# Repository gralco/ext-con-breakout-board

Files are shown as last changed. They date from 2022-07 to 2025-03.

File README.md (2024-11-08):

A breakout board for J10 on the Librem 5.

The rigid section has an overall thickness of 1.2mm, the flex section has an overall thickness of flex section is 0.126mm, and the stiffener and its adhesive adds 0.125mm on top of the thickness of the flex.

The panels were made by PCBWay, if you would like to order these yourself then you can use their product number W159429AS1D27 to reorder the same panel.

The FPC connector used is either Panasonic AXT624124 or OK-06M024-04.

Here is a photo of a v0.6 panel:
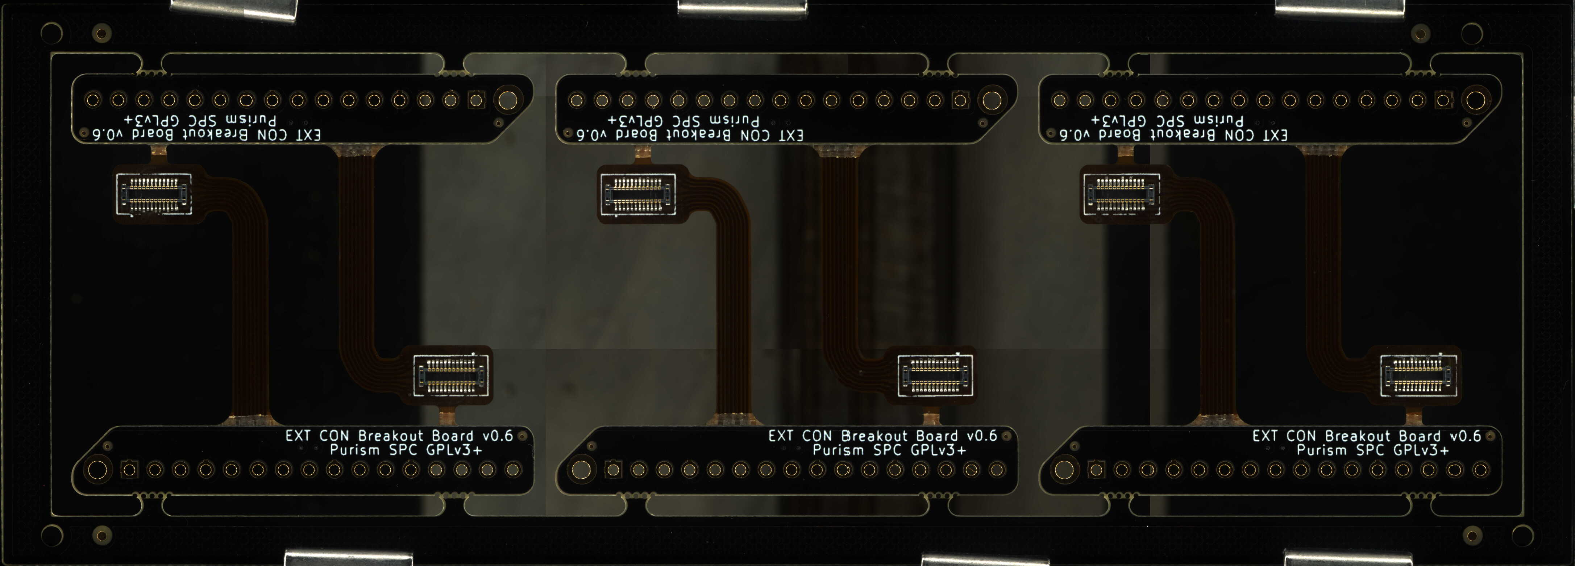
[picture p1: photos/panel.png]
Panel


Here is a photo of the rigid-flex board mounted inside a Librem 5, using the center M.2 cover screw to fasten the rigid section down:
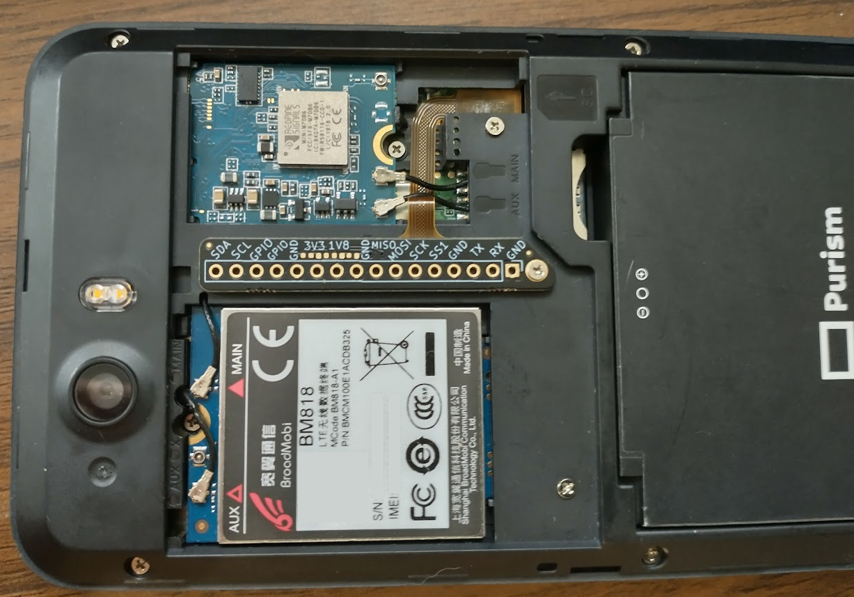
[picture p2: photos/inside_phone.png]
Mounted inside Librem 5


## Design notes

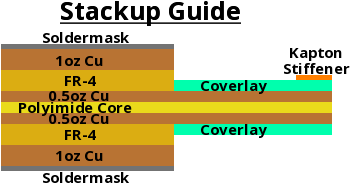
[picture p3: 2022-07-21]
stackup.png

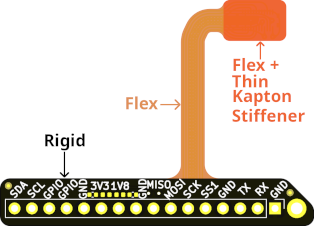
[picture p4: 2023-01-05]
ext-con-breakout-board-small.png

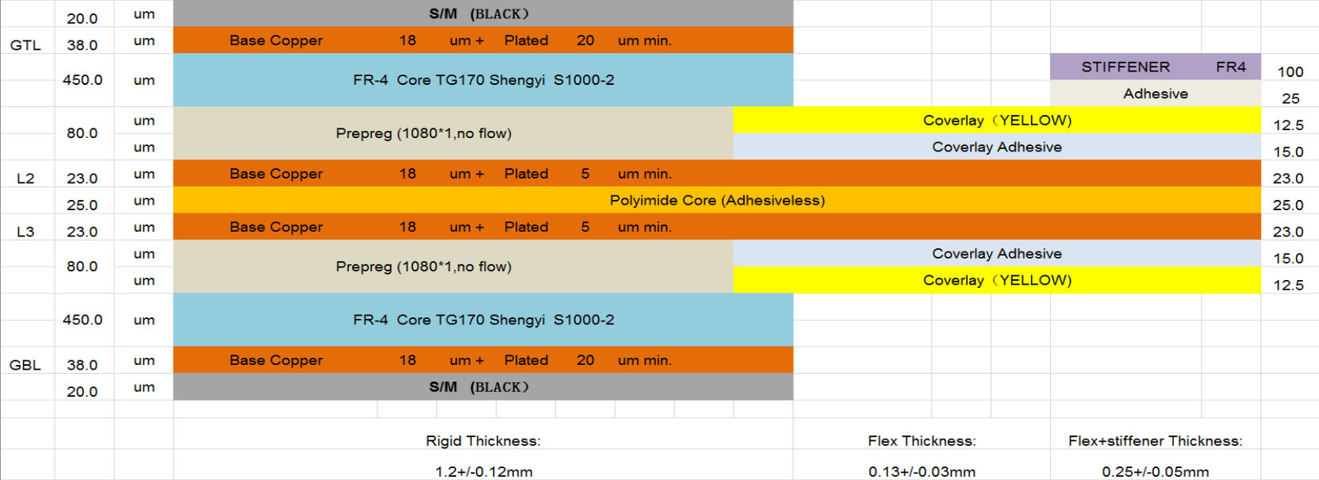
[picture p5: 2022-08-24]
final_stackup.png

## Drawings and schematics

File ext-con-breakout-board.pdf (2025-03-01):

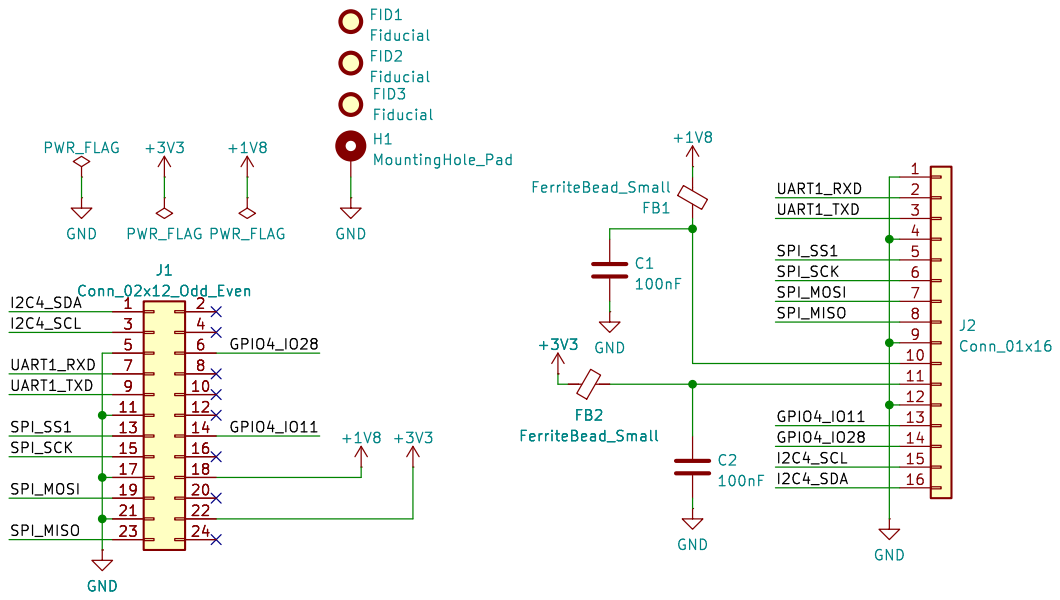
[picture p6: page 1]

File: ext-con-breakout-board.kicad_sch Sheet: / Purism SPC GNU GPLv3+

Id: 1/1 Title: EXT CON Breakout Board

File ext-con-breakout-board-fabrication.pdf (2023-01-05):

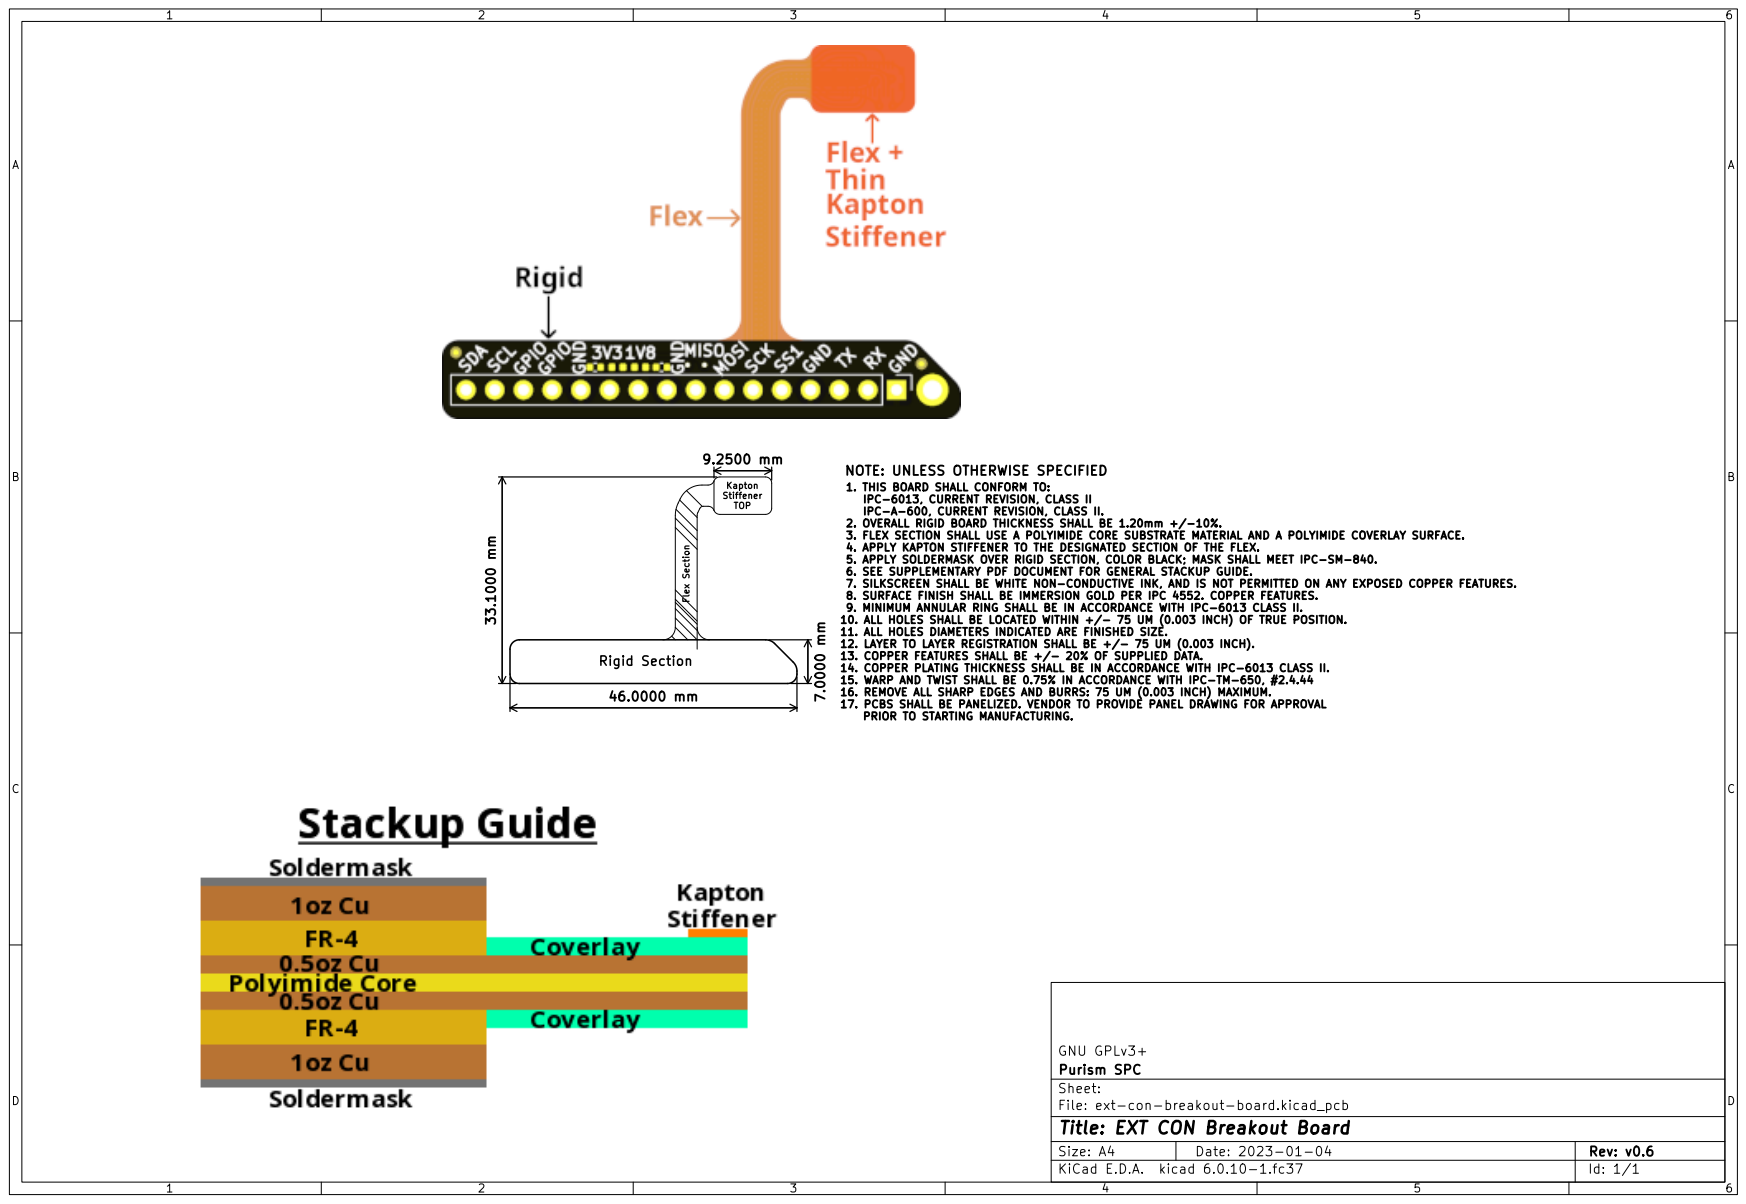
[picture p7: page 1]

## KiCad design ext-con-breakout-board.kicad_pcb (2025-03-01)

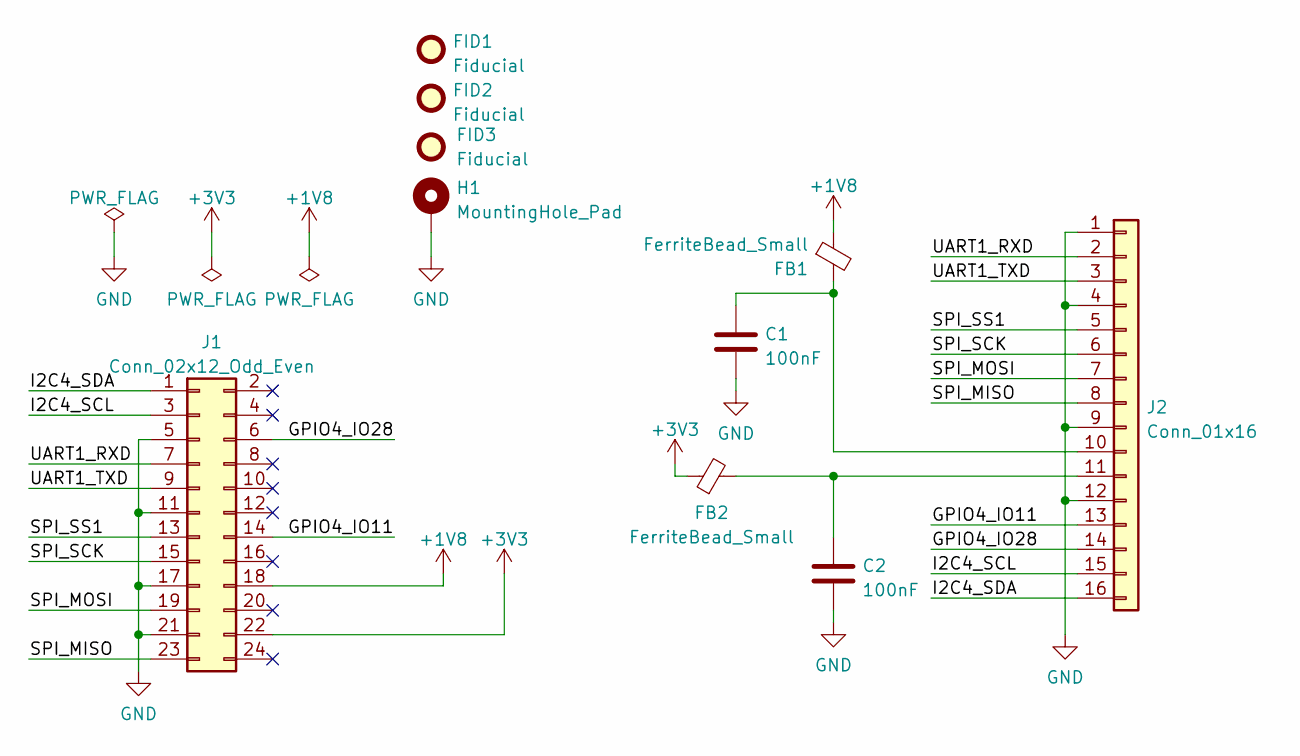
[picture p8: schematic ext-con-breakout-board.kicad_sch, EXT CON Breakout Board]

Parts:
C1, C2: 100nF; C_0402_1005Metric
FB1, FB2: FerriteBead_Small; L_0402_1005Metric
FID1, FID2, FID3: Fiducial; Fiducial_0.5mm_Mask1mm
H1: MountingHole_Pad; MountingHole_1.7mm_M1.4_Pad
J1: Conn_02x12_Odd_Even; AXT624124; MFG Part Num AXT624124
J2: Conn_01x16; PinHeader_1x16_P2.54mm_Vertical

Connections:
+1V8: FB1.1, J1.18
+3V3: FB2.1, J1.22
/GPIO4_IO11: J1.14, J2.13
/GPIO4_IO28: J1.6, J2.14
/I2C4_SCL: J1.3, J2.15
/I2C4_SDA: J1.1, J2.16
/SPI_MISO: J1.23, J2.8
/SPI_MOSI: J1.19, J2.7
/SPI_SCK: J1.15, J2.6
/SPI_SS1: J1.13, J2.5
/UART1_RXD: J1.7, J2.2
/UART1_TXD: J1.9, J2.3
GND: C1.2, C2.2, H1.1, J1.5, J1.11, J1.17, J1.21, J2.1, J2.4, J2.9, J2.12
unnamed: C1.1, FB1.2, J2.10
unnamed: C2.1, FB2.2, J2.11

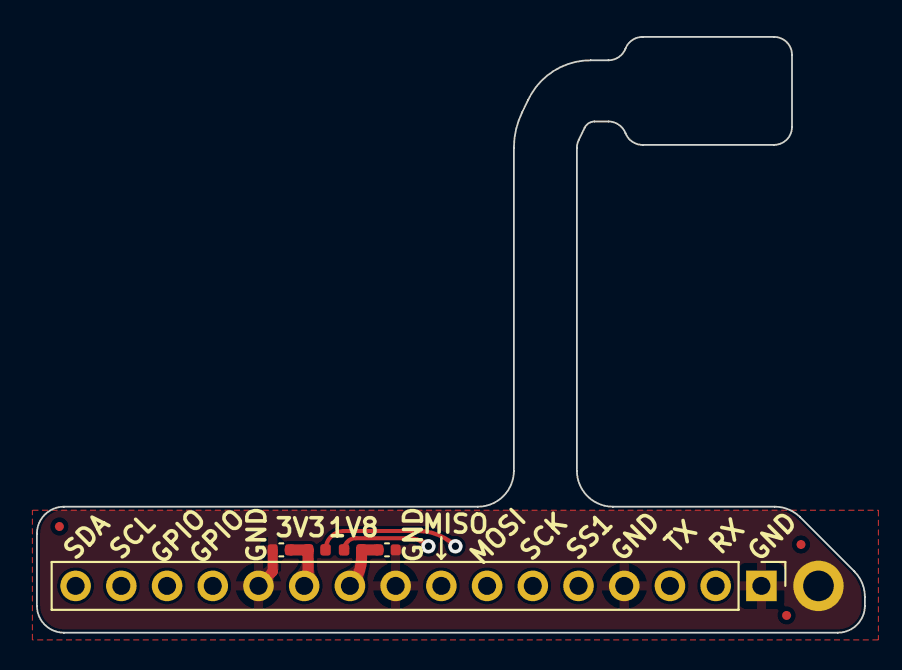
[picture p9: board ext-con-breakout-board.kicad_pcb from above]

Board: 4 copper layers, 46.0 x 33.1 mm, 10 parts (0 on the bottom side), 15 nets.

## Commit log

2022-07-13 Add the start of the project
    [ext-con-breakout-board.kicad_pcb, ext-con-breakout-board.kicad_sch]
2022-07-16 Begin fanning out the nets near the FPC connector
    [ext-con-breakout-board.kicad_pcb, ext-con-breakout-board.kicad_sch]
2022-07-19 Adjust the edge cuts based on the space available on the phone
    Rev v1.0.6 of the phone has a plastic bracket on the mid-frame which
    joins the WiFi tab holder section to the section above the smartcard
    slot. This piece bridges over the testi points and has holes where the
    test points are located.
    The intent of the edge cut design in this commit is to snake around the
    plastic mid-frame that bridges between the two sections as was
    described. If successful, this will neatly fit in the space remaining on
    a v1.0.6 phone.
    Also begin routing in this allotted space which tries to avoid the
    plastic obstructions. Since avoiding the plastic brakets requires the
    use of non-45 degree angles, this commit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
    [ext-con-breakout-board.kicad_pcb]
2022-07-20 Route the remaining portion of the FPC section and add the rigid section
    The rigid section has a mounting hole which lines up with the center
    screw that holds the M.2 cover in place. This will allow the board to be
    mounted to the back of the phone.
    Extra flex length was given to ensure enough distance to reach the
    position where the rigid section will be mounted. The drawings on the
    User.1 layer shows where the plastic obstacles are as well as the
    location of the M1.4 threaded hole. There is approximately 5.4mm of
    additional slack in the length of the flex section so that it can be
    tucked inside the volume it runs along.
    The rigid section of the board will sit between the M.2 modules, on t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
    [ext-con-breakout-board.kicad_pcb, ext-con-breakout-board.kicad_sch]
2022-07-20 Make the board 4 layers and move the flex copper to the inner layers
    The 0402 caps and ferrite beads and their traces have to remain on the
    F.Cu layer.
    This commit was accomplished by having to manually edit the .kicad_pcb
    text file in order to move the previous F.Cu & B.Cu layers to becoming
    In1.Cu & In2.Cu.
    Also add notes regarding where the rigid section is, where the flex
    section is, and that the area with the FPC connector should have a
    kapton stiffener placed there. These notes are found on the
    User.Comments layer.
    [ext-con-breakout-board.kicad_pcb]
2022-07-20 Export the manufacturing files (gerbers and PDF)
    Add fab notes on the User.Comments layer. Include a general stackup
    guide image in the PDF fabrication drawing.
    Re-centered the whole board on the canvas. The vias on the flex section
    have to be set as "buried" vias going from In1.Cu to In2.Cu in order to
    get the correct gerber export.
    [ext-con-breakout-board-B_Cu.gbr, ext-con-breakout-board-B_Mask.gbr, ext-con-breakout-board-B_Paste.gbr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]
2022-07-20 Fix the SPI_SCK and SPI_SS1 traces having slight kinks on the straight long flex section
    Re-export the gerbers after this fix is applied.
    [ext-con-breakout-board-B_Cu.gbr, ext-con-breakout-board-B_Mask.gbr, ext-con-breakout-board-B_Paste.gbr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]
2022-07-25 Add a graphic which clearly shows the rigid, flex, and stiffener sections to the fab drawing
    Add the fab drawing in this commit.
    Include the height and width dimensions of the board in the fab drawing
    and the comments auxilary layer of the gerbers.
    [ext-con-breakout-board-B_Cu.gbr, ext-con-breakout-board-B_Mask.gbr, ext-con-breakout-board-B_Paste.gbr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]
2022-07-25 Update the fab drawing to show the dimensions of the rigid section as well as the width of the kapton stiffener area
    [ext-con-breakout-board-B_Cu.gbr, ext-con-breakout-board-B_Mask.gbr, ext-con-breakout-board-B_Paste.gbr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]
2022-08-24 Add the manufacturer's (PCBWay's) panel gerbers
2022-08-24 Add photos of the panel and the board inside a phone
    Add an image of the final stackup and the answered engineering queries
    from PCBWay.
    [W159429AS1C19-EQ.ods]
2023-01-04 Swap the 3V3 and 1V8 labels on the silkscreen
    [ext-con-breakout-board.kicad_pcb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]
2023-01-05 Shrink the flex section by 3.5mm, increment the version to v0.6, re-export the fabrication drawing (PDF), and re-export the gerbers
    Also export the schematic as a PDF.
    [ext-con-breakout-board-B_Cu.gbr, ext-con-breakout-board-B_Mask.gbr, ext-con-breakout-board-B_Paste.gbr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]
2023-02-06 Replace the inside_phone.png photo with an edited one which swaps the 1V8 and 3V3 silkscreen markings to reduce the likelihood of this mistake being referenced
2023-02-06 Replace the PCBWay product number in the README to use the one for v0.6
2023-02-13 Update the project to use the KiCad 7.0 format
    [ext-con-breakout-board.kicad_pcb, ext-con-breakout-board.kicad_sch]
2023-02-23 Add the v0.6 panelized gerbers from PCBWay
    [W159429AS1C23.drl]
2023-02-27 Add the v0.6 panelized ODB++ file from PCBWay
2023-04-03 Update the README to mention that the Panasonic AXT624124 FPC connector is an option
2023-04-23 Add teardrops to the 0402 pads, add GND trace from C2 to the through hole pin, make the FPC connector part number be Panasonic AXT624124, add a 3D model for the FPC connector, fix and wave all DRCs o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
    [ext-con-breakout-board-B_Cu.gbr, ext-con-breakout-board-B_Mask.gbr, ext-con-breakout-board-B_Paste.gbr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]
2023-09-27 Add a silkscreen arrow pointing at the MISO pin
    Add a third fiducial. Reduce the thermal relief gap to 0.428mm so that
    the GND pins can have four spokes connecting to the copper pour on
    ln2.Cu.
    Fix the hatched lines drawn in the "Flex Section" on the User.Comments
    layer.
    [ext-con-breakout-board.kicad_pcb, ext-con-breakout-board.kicad_sch]
2024-05-25 Update project to KiCad 8 and use built-in teardrops
    * Add IPC-2581 file
    [ext-con-breakout-board-B_Cu.gbr, ext-con-breakout-board-B_Mask.gbr, ext-con-breakout-board-B_Paste.gbr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]
2024-11-08 README: Update the PCBWay product number for v0.6
2025-03-01 Update the project to KiCad 9.0 and fix the GND hatched copper on layer 2
    Create a .kicad_jobset file for exporting manufacturing outputs.
    [ext-con-breakout-board-B_Cu.gbr, ext-con-breakout-board-B_Mask.gbr, ext-con-breakout-board-B_Paste.gbr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]

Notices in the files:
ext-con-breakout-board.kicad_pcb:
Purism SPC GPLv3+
